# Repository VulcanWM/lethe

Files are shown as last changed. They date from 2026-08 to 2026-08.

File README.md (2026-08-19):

# Lethe

Lethe is an educational device aimed at reducing student's screen times by using a speaker to ask questions / convey informations, and using tilts to get user input.

## How it works
- load flashcard sets or MCQ sets onto the ESP32's USB-C connector (it must be in the JSON format expected by Lethe)
- select the flashcard set or MCQ set on the device by tilting through the list of all sets
- if in MCQ mode, a question will be spoken and each different direction responds an option, so to answer you tilt the device in a direction.
- the round will keep on going until all of the questions have been answered correctly
- if in flashcard mode, each flashcard's front side will be spoken out loud
- you can tilt up and down to flip the card and read the other side
- then you tilt left/right to signal whether you want it to be repeated or not

## Inspiration and component reasoning

I made it because high screen time is a problem I face myself, and this device means I can move around while studying. I also wanted to experiment and see if listening rather than reading helps to remember stuff more or not.

Some of the components I'm using and why:
- Seeed Studio XIAO ESP32-S3 Plus rather than not Plus because it has higher Flash and I'm using that to store all the flashcard sets.
- OLED display rather than a colour one because the screen will not be in use during the actual modes because I want the user to focus on sound rather than screens.
- An IMU (BMI270) so that I can accurately detect motions like tilting and flicking in all directions. This means I can use gestures instead of button clicking for user input.
- 1000 mAh LiPo Battery so that there is a reasonable battery life (5 hours) but it doesn't take too long to charge (10 hours).
- JST-PH 2-pin connector so that I can change the battery without needing to remove the solder.

## Hardware
This repository contains all the hardware files you would need to replicate this project. The PCB + schematics was done in the KiCad, and the enclosure was designed in Fusion 360.

The [`pcb-files`](pcb-files) folder contains the KiCad source files (`.kicad_sch`, `.kicad_pro`, `.kicad_pcb`) and the `gerbers.zip` which was used to manufacture the PCB.

The [`cad-files`](cad-files) folder contains `.step`, `.stl` and .`f3d` files for both the top and bottom cases of the enclosure for lethe.
## Firmware
There are 2 main components of the firmware: the code that will be uploaded onto the ESP32, and the code that will be used to transmit json sets on the user's device to the ESP32 when connected to the user's device via USB-C.

Both are located in the [`firmware-files`](firmware-files) folder: `lethe.ino` refers to the ESP32 code, and `upload.py` refers to the file transmission code.

## Assembly

The PCB is mounted to the bottom enclosure using three M2 self-tapping screws through the 2.2 mm mounting holes on the PCB and into standoffs printed as part of the enclosure. Then, the top and bottom parts of the enclosure are fitted together.

## Images
This is what the schematic looks like:
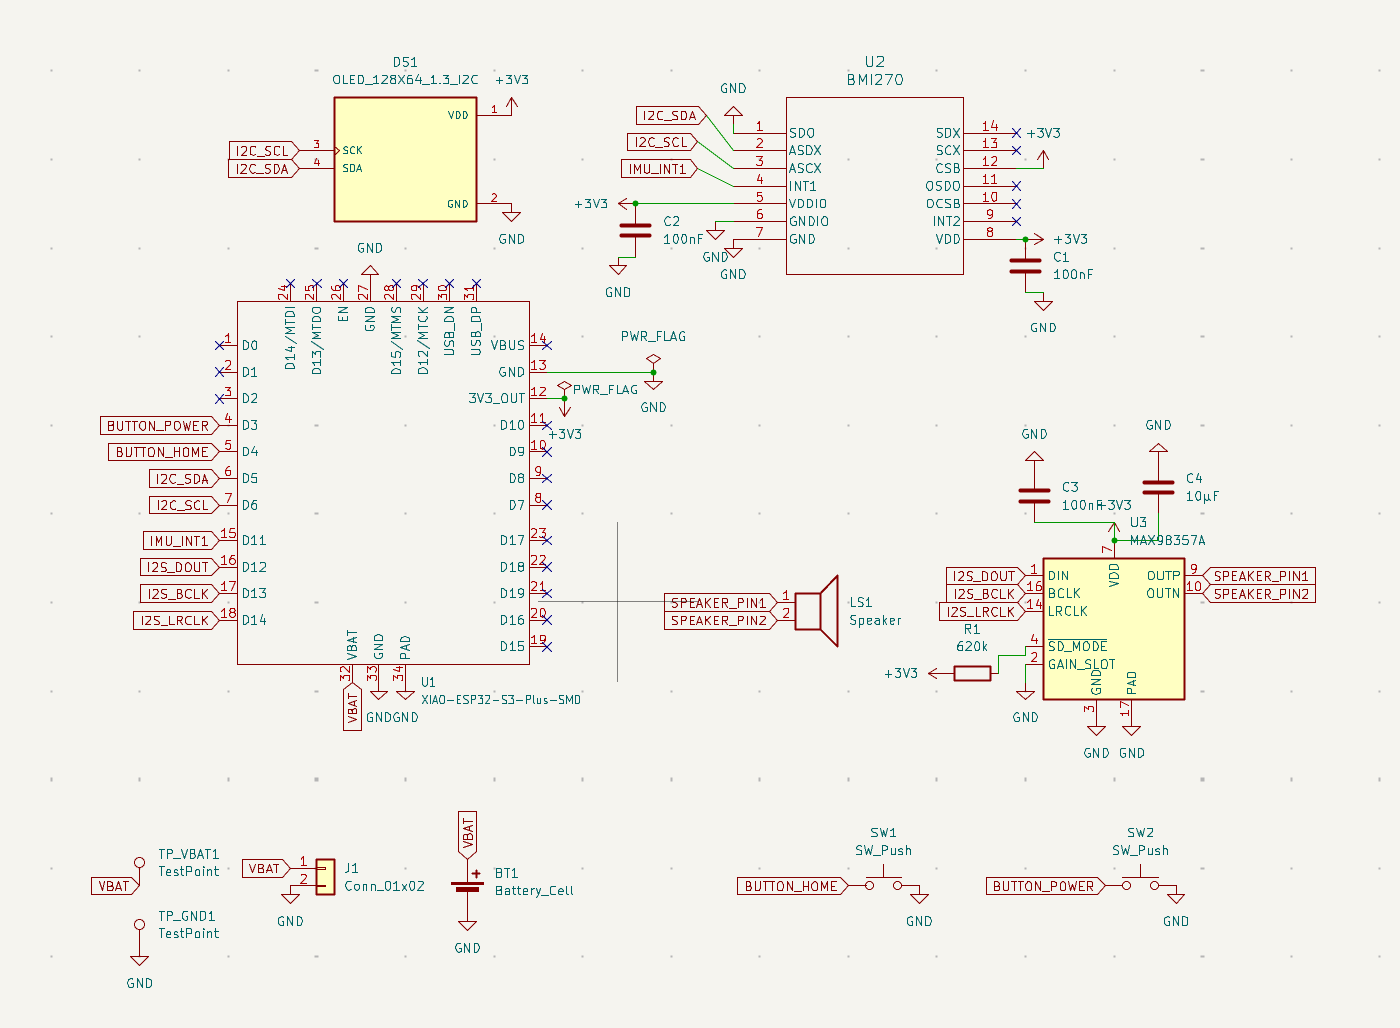
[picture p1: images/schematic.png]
schematic


This is what the PCB looks like:
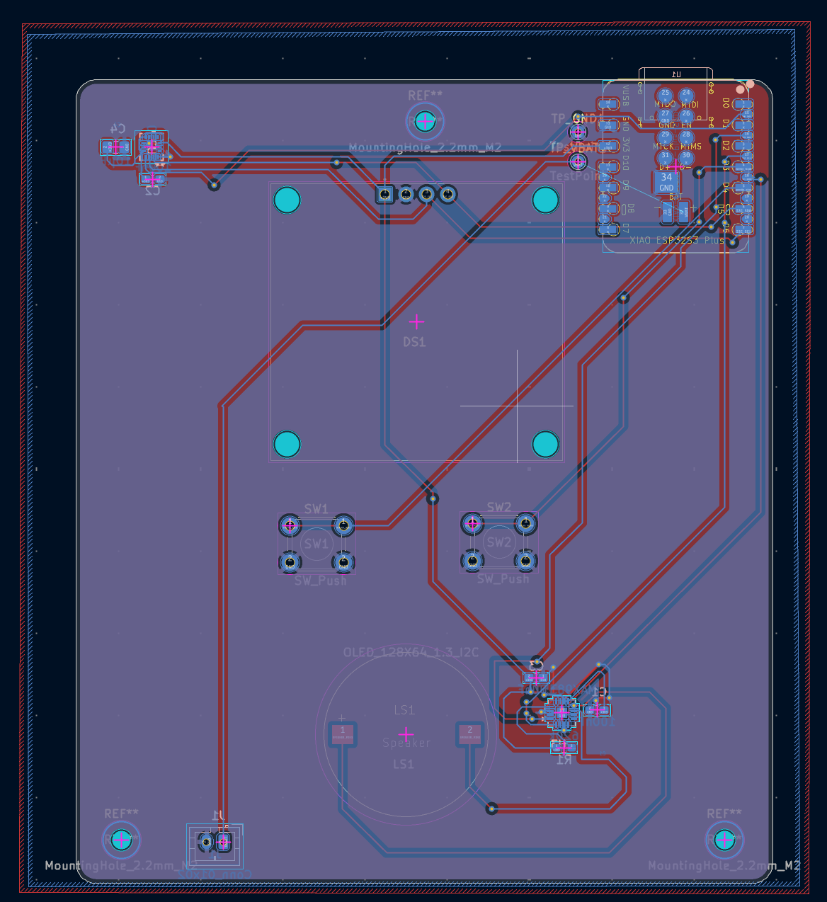
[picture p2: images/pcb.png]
pcb


This is what the enclosure (top and bottom case) looks like:
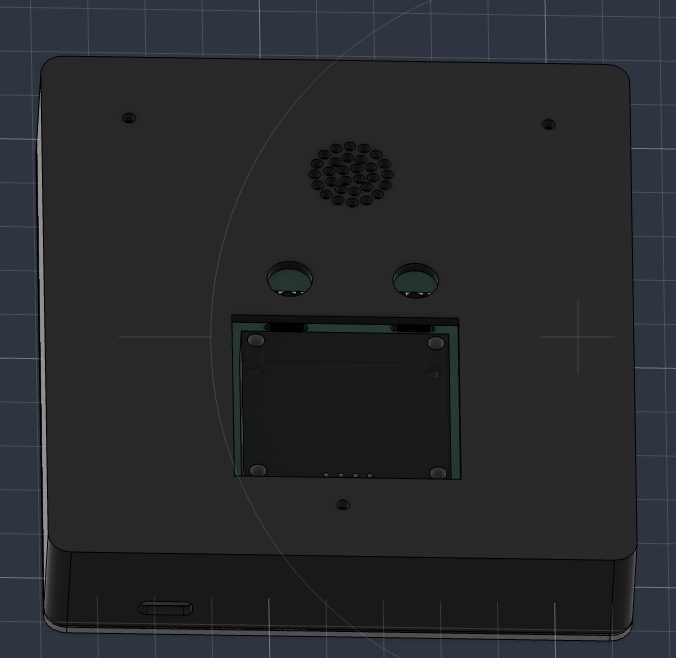
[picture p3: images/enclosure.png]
enclosure


## BOM
Also in the [BOM.csv](BOM.csv) file.

| Name | Quantity | Link To Buy | Cost (USD) |
|---|:---:|---|---|
| Seeed Studio XIAO ESP32-S3 Plus | 1 | [Seeed Studio](https://www.seeedstudio.com/Seeed-Studio-XIAO-ESP32S3-Plus-p-6361.html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) | $7.90 (+$3.80 shipping)  |
| Bosch BMI270 | 1 | [LCSC](https://www.lcsc.com/product-detail/C2836813.html?s_z=n_q_x_BMI270) | $3.64 |
| MAX98357A | 1 | [LCSC](https://www.lcsc.com/product-detail/C910544.html) | $1.34 |
| 1.3" SH1106 OLED | 1 | [AliExpress](https://www.aliexpress.com/item/1005006099414855.html) | $4.17 (shipping unknown) |
| JST-PH 2-pin Connector | 1 | [LCSC](https://www.lcsc.com/product-detail/C131337.html) | $0.71 for 20 |
| 20 mm 8Ω Speaker | 1 | [LCSC](https://www.lcsc.com/product-detail/C28642279.html) | $0.85 |
| Button | 2 | [LCSC](https://www.lcsc.com/product-detail/C393938.html) | $0.97 for 50 |
| 620 kΩ Resistor | 1 | [LCSC](https://www.lcsc.com/product-detail/C2096268.html) | $0.01 |
| 100 nF Ceramic Capacitor | 3 | [LCSC](https://www.lcsc.com/product-detail/C92490.html) | $1.81 for 50 |
| 10 µF Ceramic Capacitor | 1 | [LCSC](https://www.lcsc.com/product-detail/C17024.html) | $1.95 for 20 |
| 1000 mAh LiPo Battery | 1 | [AliExpress](https://www.aliexpress.com/item/1005009294502730.html) | $6.87 |
| **Total** | | | **$34.02 (excluding unknown AliExpress shipping)** |

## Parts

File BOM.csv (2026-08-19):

Name | Quantity | Link To Buy | Cost (USD)
Seeed Studio XIAO ESP32-S3 Plus | 1 | https://www.seeedstudio.com/Seeed-Studio-XIAO-ESP32S3-Plus-p-6361.html | $7.90 (+$3.80 shipping)
Bosch BMI270 | 1 | https://www.lcsc.com/product-detail/C2836813.html?s_z=n_q_x_BMI270 | $3.64
MAX98357A | 1 | https://www.lcsc.com/product-detail/C910544.html?s_z=n_q_MAX98357AETE%2520T | $1.34
1.3 inch SH1106 OLED | 1 | https://www.aliexpress.com/item/1005006099414855.html | $4.17 (shipping unknown)
JST-PH 2-pin Connector | 1 | https://www.lcsc.com/product-detail/C131337.html?s_z=n_q_JST%2520B2B-PH-K-S%28LF%29%28SN%29 | $0.71 for 20
20 mm 8 ohm Speaker | 1 | https://www.lcsc.com/product-detail/C28642279.html?s_z=n_q_20mm%25208ohm%2520speaker | $0.85
Button | 2 | https://www.lcsc.com/product-detail/C393938.html?s_z=n_q_SHOU%2520HAN%2520TS665CJ | $0.97 for 50
620 kΩ Resistor | 1 | https://www.lcsc.com/product-detail/C2096268.html?s_z=s_p_CRG0603F620K | $0.01
100 nF Ceramic Capacitor | 3 | https://www.lcsc.com/product-detail/C92490.html?s_z=n_q_100nF%25200603%2520X7R%252025V | $1.81 for 50
10 µF Ceramic Capacitor | 1 | https://www.lcsc.com/product-detail/C17024.html?s_z=n_q_10uF%25200805%2520X5R%252010V | $1.95 for 20
1000 mAh LiPo Battery | 1 | https://www.aliexpress.com/item/1005009294502730.html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 | $6.87
Total |  |  | $34.02 (excluding unknown AliExpress shipping)

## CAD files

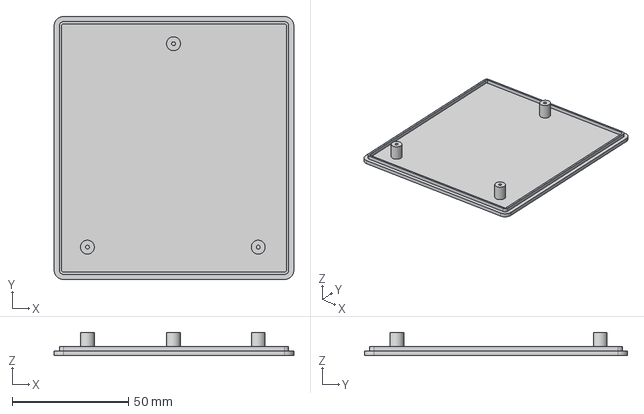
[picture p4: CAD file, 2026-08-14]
cad-files/bottom-case/BottomCase.step
103.0 x 113.0 x 10.0 mm

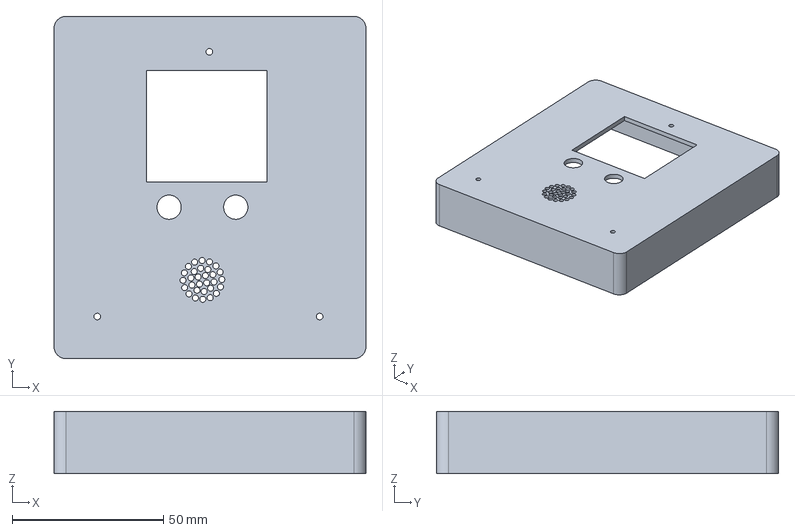
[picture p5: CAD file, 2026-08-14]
cad-files/top-case/TopCase.step
103.0 x 113.0 x 20.5 mm

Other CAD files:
cad-files/bottom-case/BottomCase.f3d
cad-files/bottom-case/BottomCase.stl
cad-files/top-case/TopCase.f3d
cad-files/top-case/TopCase.stl

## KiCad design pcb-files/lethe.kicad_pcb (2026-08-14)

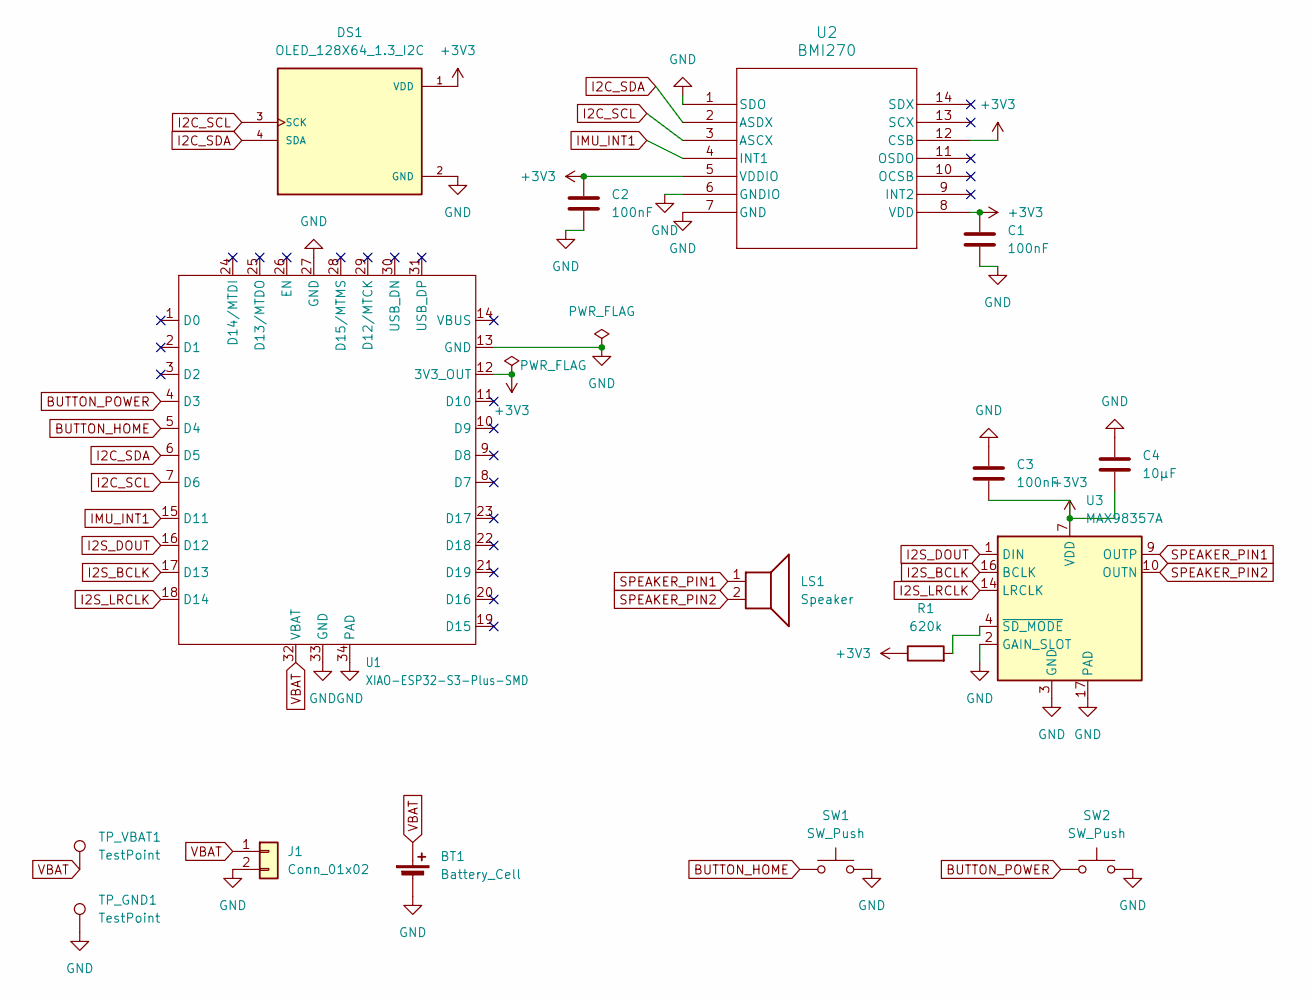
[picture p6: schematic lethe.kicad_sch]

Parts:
BT1: Battery_Cell
C1, C2, C3: 100nF; C_0603_1608Metric_Pad1.08x0.95mm_HandSolder
C4: 10µF; C_0805_2012Metric_Pad1.18x1.45mm_HandSolder
DS1: OLED_128X64_1.3_I2C; LCD_OLED_128X64_1.3_I2C; PARTREV NA
J1: Conn_01x02; JST_PH_B2B-PH-K_1x02_P2.00mm_Vertical
LS1: Speaker; Speaker_HDK2008AA_1P2_20mm
R1: 620k; R_0603_1608Metric_Pad0.98x0.95mm_HandSolder
SW1, SW2: SW_Push; SW_PUSH_6mm_H5mm
TP_GND1: TestPoint; TestPoint_THTPad_D1.5mm_Drill0.7mm
TP_VBAT1: TestPoint; TestPoint_THTPad_D1.5mm_Drill0.7mm
U1: XIAO-ESP32-S3-Plus-SMD
U2: BMI270; BMI270_BOS
U3: MAX98357A; TQFN-16-1EP_3x3mm_P0.5mm_EP1.23x1.23mm

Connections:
+3V3: C1.1, C2.1, C3.2, C4.2, DS1.1 (VDD), R1.1, U1.12 (3V3_OUT), U2.5 (VDDIO), U2.8 (VDD), U2.12 (CSB), U3.7 (VDD), U3.8 (VDD)
BUTTON_HOME: SW1.1, U1.5 (D4)
BUTTON_POWER: SW2.1, U1.4 (D3)
GND: BT1.2 (-), C1.2, C2.2, C3.1, C4.1, DS1.2 (GND), J1.2, SW1.2, SW2.2, TP_GND1.1 (1_1), U1.13 (GND), U1.27 (GND), U1.33 (GND), U1.34 (PAD), U2.1 (SDO), U2.6 (GNDIO), U2.7 (GND), U3.2 (GAIN_SLOT), U3.3 (GND), U3.11 (GND), U3.15 (GND), U3.17 (PAD)
I2C_SCL: DS1.3 (SCK), U1.7 (D6), U2.3 (ASCX)
I2C_SDA: DS1.4 (SDA), U1.6 (D5), U2.2 (ASDX)
I2S_BCLK: U1.17 (D13), U3.16 (BCLK)
I2S_DOUT: U1.16 (D12), U3.1 (DIN)
I2S_LRCLK: U1.18 (D14), U3.14 (LRCLK)
IMU_INT1: U1.15 (D11), U2.4 (INT1)
unnamed: R1.2, U3.4 (~SD_MODE)
SPEAKER_PIN1: LS1.1, U3.9 (OUTP)
SPEAKER_PIN2: LS1.2, U3.10 (OUTN)
VBAT: BT1.1 (+), J1.1, TP_VBAT1.1 (1_1), U1.32 (VBAT)

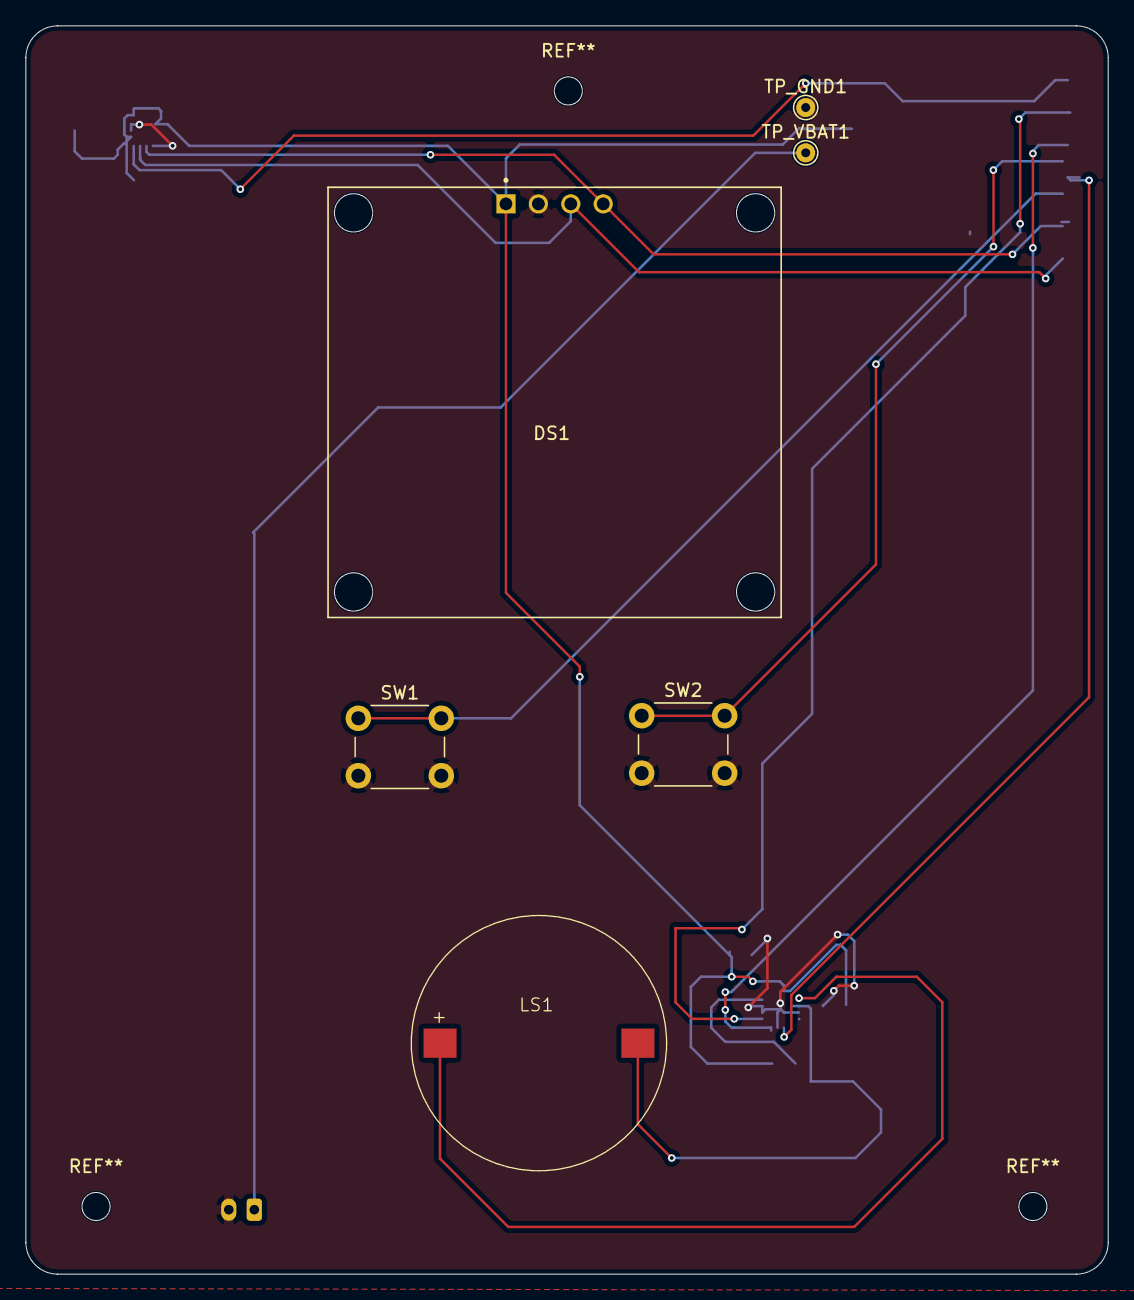
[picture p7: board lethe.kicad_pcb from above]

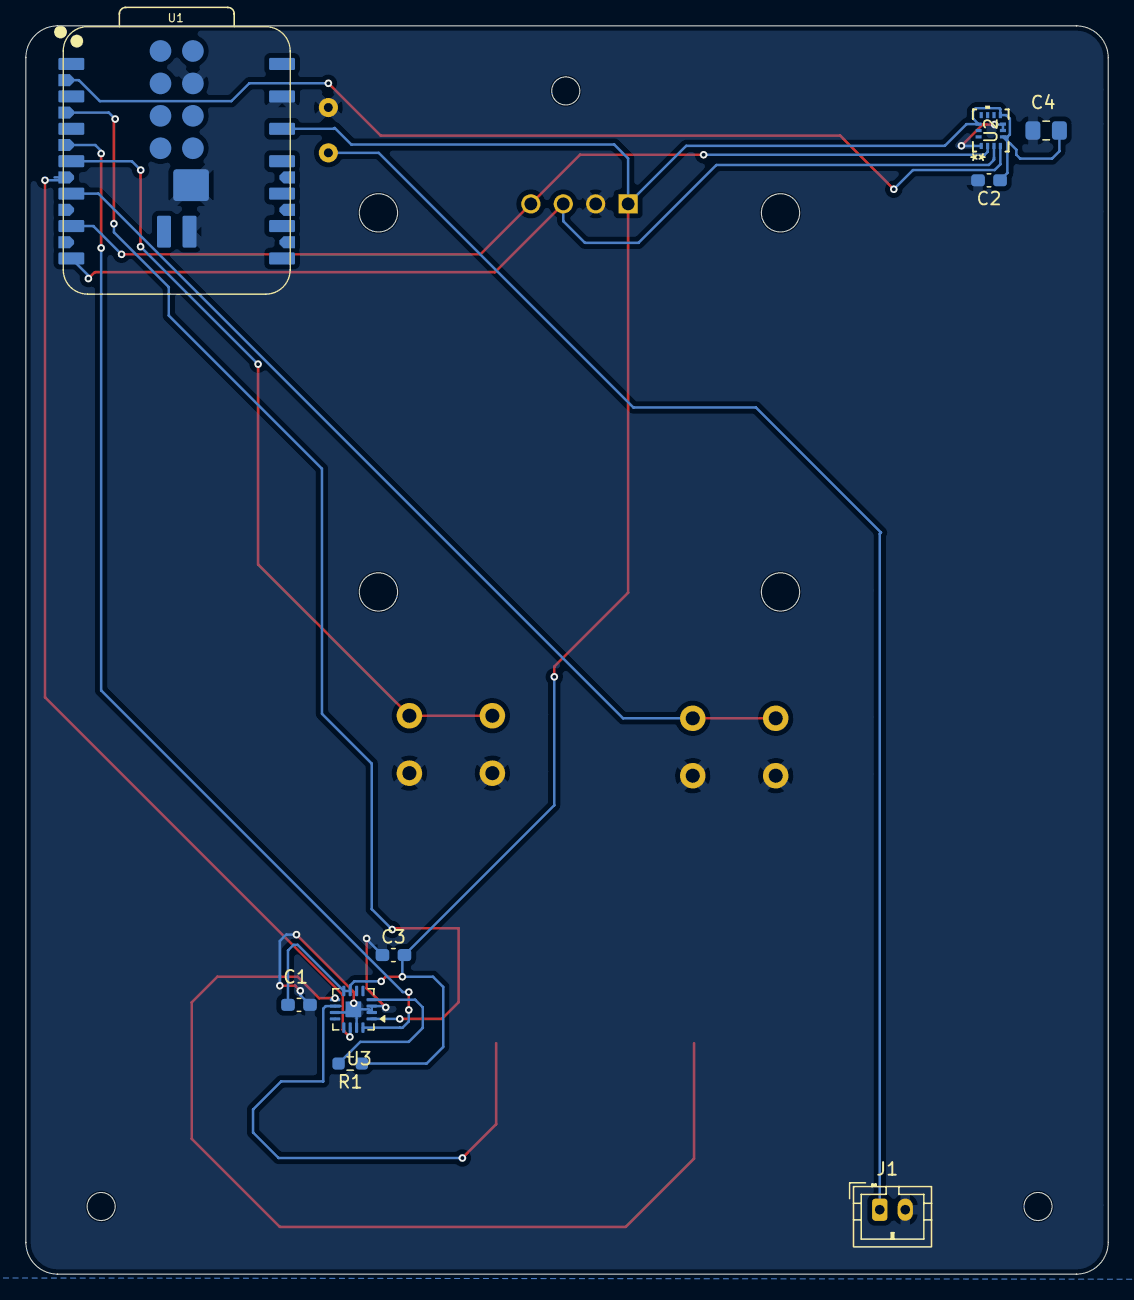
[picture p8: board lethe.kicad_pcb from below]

Board: 2 copper layers, 84.8 x 97.8 mm, 15 parts (9 on the bottom side), 14 nets.

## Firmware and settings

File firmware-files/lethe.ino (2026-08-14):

#include <Wire.h>
#include <U8g2lib.h>
#include <7Semi_BMI270.h>
#include <BackgroundAudioSpeech.h>
#include <ESP32I2SAudio.h>
#include <libespeak-ng/voice/en.h>
#include <esp_sleep.h>
#include "FS.h"
#include <LittleFS.h>
#include <ArduinoJson.h>
#include <vector>

// buttons
#define BUTTON_POWER D3
#define BUTTON_HOME D4

// i2c (for oled and imu)
#define SDA_PIN D5
#define SCL_PIN D6

// imu interrupt
#define IMU_INT1 D11

// i2s (for amplifier)
#define I2S_DOUT D12
#define I2S_BCLK D13
#define I2S_LRCLK D14

// for LittleFS
#define FORMAT_LITTLEFS_IF_FAILED true

bool initDirectories(){
  if (!LittleFS.exists("/mcqs")){
    if (!LittleFS.mkdir("/mcqs")){
      Serial.println("failed to create mcqs directory");
      return false;
    }
  };

  if (!LittleFS.exists("/flashcards")){
    if (!LittleFS.mkdir("/flashcards")){
      Serial.println("failed to create flashcards directory");
      return false;
    }
  };

  return true;
}

U8G2_SH1106_128X64_NONAME_F_HW_I2C display(
  U8G2_R0,
  U8X8_PIN_NONE
);

BMI270_7Semi imu;

ESP32I2SAudio audio(
  I2S_BCLK,
  I2S_LRCLK,
  I2S_DOUT
);

BackgroundAudioSpeech speech(audio);

enum Gesture {
  NONE,

  TILT_UP,
  TILT_DOWN,
  TILT_LEFT,
  TILT_RIGHT,

  FLICK_UP,
  FLICK_DOWN,
  FLICK_LEFT,
  FLICK_RIGHT,

  SPIN,
};

enum TILT_STATE {
  TILT_NEUTRAL,
  TILT_WAITING_RETURN_RIGHT,
  TILT_WAITING_RETURN_LEFT,
  TILT_WAITING_RETURN_UP,
  TILT_WAITING_RETURN_DOWN
};

enum FLICK_STATE {
  FLICK_NEUTRAL,
  FLICK_WAITING_RETURN_RIGHT,
  FLICK_WAITING_RETURN_LEFT,
  FLICK_WAITING_RETURN_UP,
  FLICK_WAITING_RETURN_DOWN,
};

enum FACE_STATE {
  FACE_UP,
  FACE_DOWN
};

enum DEVICE_STATE {
  HOME,
  MCQ_SET_MENU,
  FLASHCARD_SET_MENU,
  MCQ_ACTIVE,
  FLASHCARD_ACTIVE
};

const char* gestureToString(Gesture gesture);
Gesture detectTilt(float ax, float ay, float az);
Gesture detectFlick(float ax, float ay, float az);
Gesture detectSpin(float ax, float ay, float az);
Gesture detectGesture(float ax, float ay, float az);

TILT_STATE tiltState = TILT_NEUTRAL;
FLICK_STATE flickState = FLICK_NEUTRAL;
FACE_STATE faceState = FACE_UP;
DEVICE_STATE deviceState = HOME;

bool mcqSetsChanged = true;
bool flashcardSetsChanged = true;
String setSelected;

const char* gestureToString(Gesture gesture){
  switch (gesture){
    case TILT_UP: return "tilt up";
    case TILT_DOWN: return "tilt down";
    case TILT_LEFT: return "tilt left";
    case TILT_RIGHT: return "tilt right";

    case FLICK_UP: return "flick up";
    case FLICK_DOWN: return "flick down";
    case FLICK_LEFT: return "flick left";
    case FLICK_RIGHT: return "flick right";

    case SPIN: return "spin";

    default: return "none";
  }
}

Gesture detectTilt(float ax, float ay, float az){
  const float tiltThreshold = 0.7;
  const float neutralThreshold = 0.25;

  if (tiltState == TILT_NEUTRAL){
    if (ax > tiltThreshold){
      tiltState = TILT_WAITING_RETURN_RIGHT;
    }
    else if (ax < (-1 * tiltThreshold)){
      tiltState = TILT_WAITING_RETURN_LEFT;
    }
    else if (ay > tiltThreshold){
      tiltState = TILT_WAITING_RETURN_UP;
    }
    else if (ay < (-1 * tiltThreshold)){
      tiltState = TILT_WAITING_RETURN_DOWN;
    }
  }

  if (tiltState == TILT_WAITING_RETURN_DOWN){
    if (abs(ax) < neutralThreshold && abs(ay) < neutralThreshold){
      tiltState = TILT_NEUTRAL;
      return TILT_DOWN;
    }
  }
  if (tiltState == TILT_WAITING_RETURN_UP) {
    if (abs(ax) < neutralThreshold && abs(ay) < neutralThreshold){
      tiltState = TILT_NEUTRAL;
      return TILT_UP;
    }
  }

  if (tiltState == TILT_WAITING_RETURN_LEFT){
    if (abs(ax) < neutralThreshold && abs(ay) < neutralThreshold){
      tiltState = TILT_NEUTRAL;
      return TILT_LEFT;
    }
  }

  if (tiltState == TILT_WAITING_RETURN_RIGHT){
    if (abs(ax) < neutralThreshold && abs(ay) < neutralThreshold){
      tiltState = TILT_NEUTRAL;
      return TILT_RIGHT;
    }
  }
  return NONE;
}

Gesture detectFlick(float ax, float ay, float az){
  const float flickThreshold = 1.5;
  const float neutralThreshold = 0.25;

  if (flickState == FLICK_NEUTRAL){
    if (ax > flickThreshold){
      flickState = FLICK_WAITING_RETURN_RIGHT;
    }
    else if (ax < (-1 * flickThreshold)){
      flickState = FLICK_WAITING_RETURN_LEFT;
    }
    else if (ay > flickThreshold){
      flickState = FLICK_WAITING_RETURN_UP;
    }
    else if (ay < (-1 * flickThreshold)){
      flickState = FLICK_WAITING_RETURN_DOWN;
    }
  }

  if (flickState == FLICK_WAITING_RETURN_DOWN){
    if (abs(ax) < neutralThreshold && abs(ay) < neutralThreshold){
      flickState = FLICK_NEUTRAL;
      return FLICK_DOWN;
    }
  }
  if (flickState == FLICK_WAITING_RETURN_UP) {
    if (abs(ax) < neutralThreshold && abs(ay) < neutralThreshold){
      flickState = FLICK_NEUTRAL;
      return FLICK_UP;
    }
  }

  if (flickState == FLICK_WAITING_RETURN_LEFT){
    if (abs(ax) < neutralThreshold && abs(ay) < neutralThreshold){
      flickState = FLICK_NEUTRAL;
      return FLICK_LEFT;
    }
  }

  if (flickState == FLICK_WAITING_RETURN_RIGHT){
    if (abs(ax) < neutralThreshold && abs(ay) < neutralThreshold){
      flickState = FLICK_NEUTRAL;
      return FLICK_RIGHT;
    }
  }
  return NONE;
}

Gesture detectSpin(float ax, float ay, float az){
  const float faceDownThreshold = -0.8;
  const float faceUpThreshold = 0.8;

  if (faceState == FACE_UP && az < faceDownThreshold){
    faceState = FACE_DOWN;
  }

  if (faceState == FACE_DOWN && az > faceUpThreshold){
    faceState = FACE_UP;
    return SPIN;
  }

  return NONE;
}

Gesture detectGesture(float ax, float ay, float az){
  Gesture gesture;

  if (flickState != FLICK_NEUTRAL){
    return detectFlick(ax, ay, az);
  }

  if (tiltState != TILT_NEUTRAL){
    return detectTilt(ax, ay, az);
  }

  if (faceState != FACE_UP){
    return detectSpin(ax, ay, az);
  }

  gesture = detectFlick(ax, ay, az);
  if (flickState != FLICK_NEUTRAL){
    return gesture;
  }

  gesture = detectTilt(ax, ay, az);
  if (tiltState != TILT_NEUTRAL){
    return gesture;
  }

  gesture = detectSpin(ax, ay, az);
  return gesture;
}

void powerOff(){
  display.clearBuffer();
  display.sendBuffer();

  speech.flush();

  delay(100);

  esp_sleep_enable_ext0_wakeup(
    (gpio_num_t)BUTTON_POWER,
    0
  );

  esp_deep_sleep_start();
}

bool validateMCQJSON(const String& json){
  JsonDocument doc;

  DeserializationError error = deserializeJson(doc, json);

  if (error){
    Serial.println("invalid json");
    return false;
  }

  if (!doc["name"].is<const char*>()){
    Serial.println("missing/invalid name");
    return false;
  }

  if (!doc["questions"].is<JsonArray>()){
    Serial.println("missing questions array");
    return false;
  }

  JsonArray questions = doc["questions"];

  if (questions.size() == 0){
    Serial.println("no questions");
    return false;
  }

  for (JsonObject question: questions){
    if (!question["question"].is<const char*>()){
      Serial.println("invalid question");
      return false;
    }

    if (!question["options"].is<JsonArray>()){
      Serial.println("ERROR: missing/invalid options");
      return false;
    }

    JsonArray options = question["options"];

    if (options.size() < 2 || options.size() > 4){
      Serial.println("mcq must have between 2 and 4 options");
      return false;
    }

    for (JsonVariant option: options){
      if (!option.is<const char*>()){
        Serial.println("option must be text");
        return false;
      }
    }

    if (!question["answer"].is<int>()){
      Serial.println("invalid answer");
      return false;
    }

    int answer = question["answer"];
    if (answer < 0 || answer >= options.size()){
      Serial.print("answer must be between 0-");
      Serial.println(options.size()-1);
      return false;
    }
  }

  return true;
}

bool validateFlashcardJSON(const String& json){
  JsonDocument doc;

  DeserializationError error = deserializeJson(doc, json);

  if (error){
    Serial.println("ERROR: invalid json");
    return false;
  }

  if (!doc["name"].is<const char*>()){
    Serial.println("ERROR: missing/invalid json");
    return false;
  }

  if (!doc["cards"].is<JsonArray>()){
    Serial.println("ERROR: missing cards array");
    return false;
  }

  JsonArray cards = doc["cards"];

  if (cards.size() == 0){
    Serial.println("ERROR: no flashcards");
    return false;
  }

  for (JsonObject card: cards){
    if (!card["front"].is<const char*>()){
      Serial.println("ERROR: invalid front");
      return false;
    }

    if (!card["back"].is<const char*>()){
      Serial.println("ERROR: invalid back");
      return false;
    }
  }

  return true;
}

bool validateSet(const String& type, const String& json){
  if (type == "MCQ"){
    return validateMCQJSON(json);
  }

  if (type == "FLASHCARD"){
    return validateFlashcardJSON(json);
  }

  return false;
}

bool validateTempFile(const String& type){
  File file = LittleFS.open("/tmp.json", FILE_READ);

  if (!file){
    Serial.println("ERROR: failed to open temp file");
    return false;
  }

  String json = file.readString();
  file.close();

  return validateSet(type, json);
}

JsonDocument parseMCQSet(const String& setName){
  JsonDocument doc;

  String filePath = "/mcqs/" + setName;

  if (!LittleFS.exists(filePath)){
    Serial.println("file does not exist");
    return doc;
  }

  File file = LittleFS.open(filePath);
  if (!file){
    Serial.println("file is not opening");
    return doc;
  }

  String json = file.readString();
  file.close();

  DeserializationError error = deserializeJson(doc, json);

  return doc;
}

JsonDocument parseFlashcardSet(const String& setName){
  JsonDocument doc;

  String filePath = "/flashcards/" + setName;

  if (!LittleFS.exists(filePath)){
    Serial.println("file does not exist");
    return doc;
  }

  File file = LittleFS.open(filePath);
  if (!file){
    Serial.println("file is not opening");
    return doc;
  }

  String json = file.readString();
  file.close();

  DeserializationError error = deserializeJson(doc, json);

  return doc;
}

bool moveTempFile(const String& finalPath){
  if (LittleFS.exists(finalPath)){
    LittleFS.remove(finalPath);
  }

  if (!LittleFS.rename("/tmp.json", finalPath)){
    Serial.println("ERROR: failed to move temp file");
    return false;
  }

  return true;
}

void checkUSB(){
  if (Serial.available()){
    String command = Serial.readStringUntil('\n');
    command.trim();

    if (command == "PING"){
      Serial.println("PONG");
      return;
    }

    if (command == "UPLOAD"){
      String type = Serial.readStringUntil('\n');
      String name = Serial.readStringUntil('\n');
      String sizeString = Serial.readStringUntil('\n');

      type.trim();
      name.trim();
      sizeString.trim();

      size_t fileSize = sizeString.toInt();

      if (name.length() == 0 ||
          name.indexOf('/') != -1 ||
          name.indexOf('\\') != -1 ||
          !name.endsWith(".json")){
        Serial.println("ERROR: invalid filename");
        return;
      }

      String finalPath;

      if (type == "MCQ"){
        finalPath = "/mcqs/" + name;
      } else if (type == "FLASHCARD"){
        finalPath = "/flashcards/" + name;
      } else {
        Serial.println("ERROR: invalid type");
        return;
      }

      if (LittleFS.exists("/tmp.json")){
        LittleFS.remove("/tmp.json");
      }

      File tempFile = LittleFS.open("/tmp.json", FILE_WRITE);
      if (!tempFile){
        Serial.println("ERROR: failed to open temp file");
        return;
      }

      size_t received = 0;

      while (received < fileSize){
        if (Serial.available()){
          uint8_t byte = Serial.read();
          tempFile.write(byte);
          received++;
        }
      }

      tempFile.close();

      if (!validateTempFile(type)){
        Serial.println("ERROR: invalid set");
        LittleFS.remove("/tmp.json");
        return;
      }

      if (!moveTempFile(finalPath)){
        Serial.println("ERROR: could not copy file into directory");
        LittleFS.remove("/tmp.json");
        return;
      }

      if (type == "MCQ"){
        mcqSetsChanged = true;
      } else if (type == "FLASHCARD"){
        flashcardSetsChanged = true;
      }

      Serial.println("OK");
    }
  }
}

void checkPowerButton(){
  static unsigned long pressedAt = 0;
  static bool holding = false;

  bool pressed = digitalRead(BUTTON_POWER) == LOW;

  if (pressed && !holding){
    holding = true;
    pressedAt = millis();
  }

  if (!pressed){
    holding = false;
  }

  if (holding && millis() - pressedAt >= 2000){
    powerOff();
  }
}

void checkHomeButton(){
  static bool wasPressed = false;

  bool pressed = digitalRead(BUTTON_HOME) == LOW;

  if (pressed && !wasPressed){
    display.clearBuffer();
    display.sendBuffer();

    speech.flush();
    deviceState = HOME;
  }

  wasPressed = pressed;
}

std::vector<String> getAllFlashcardSets(){
  std::vector<String> sets;
  File root = LittleFS.open("/flashcards");

  File file = root.openNextFile();

  if (!root || !root.isDirectory()){
    Serial.println("failed to open flashcards directory");
    return sets;
  }

  while (file){
    if (!file.isDirectory()){
      sets.push_back(String(file.name()));
    }

    file = root.openNextFile();
  }

  return sets;
}

std::vector<String> getAllMCQSets(){
  std::vector<String> sets;
  File root = LittleFS.open("/mcqs");

  if (!root || !root.isDirectory()){
    Serial.println("failed to open mcqs directory");
    return sets;
  }

  File file = root.openNextFile();
  while (file){
    if (!file.isDirectory()){
      sets.push_back(String(file.name()));
    }

    file = root.openNextFile();
  }

  return sets;
}

void updateHome(){
  static bool willNeedRender = true;
  static int menuOptionSelected = 0;

  float ax, ay, az;
  if (imu.readAccel(ax, ay, az)) {
    Gesture gesture = detectGesture(ax, ay, az);
    if (gesture == TILT_UP){
      if (menuOptionSelected == 1){
        menuOptionSelected = 0;
        willNeedRender = true;
      }
    }
    else if (gesture == TILT_DOWN){
      if (menuOptionSelected == 0){
        menuOptionSelected = 1;
        willNeedRender = true;
      }
    }
    else if (gesture == TILT_RIGHT){
      if (menuOptionSelected == 0){
        deviceState = MCQ_SET_MENU;
      } else {
        deviceState = FLASHCARD_SET_MENU;
      }
      willNeedRender = true;
      return;
    }
  }

  if (willNeedRender){
    display.clearBuffer();
    display.setFont(u8g2_font_6x12_tf);
    display.setCursor(0, 10);
    display.print("lethe");

    display.setCursor(0, 20);
    if (menuOptionSelected == 0){
      display.print("> MCQs");
    } else {
      display.print(" MCQs");
    }

    display.setCursor(0, 30);
    if (menuOptionSelected == 1){
      display.print("> Flashcards");
    } else {
      display.print("Flashcards");
    }

    display.sendBuffer();
    willNeedRender = false;
  }
}

void updateMCQMenu(){
  static bool willNeedRender = true;
  static int menuOptionSelected = 0;
  static std::vector<String> sets = getAllMCQSets();

  if (mcqSetsChanged){
    sets = getAllMCQSets();
    mcqSetsChanged = false;

    menuOptionSelected = 0;
    willNeedRender = true;
  }

  float ax, ay, az;
  if (imu.readAccel(ax, ay, az)) {
    Gesture gesture = detectGesture(ax, ay, az);
    if (gesture == TILT_UP){
      if (!sets.empty() && menuOptionSelected != 0){
        menuOptionSelected -= 1;
        willNeedRender = true;
      }
    }
    else if (gesture == TILT_DOWN){
      if (!sets.empty() && menuOptionSelected != sets.size() - 1){
        menuOptionSelected += 1;
        willNeedRender = true;
      }
    }
    else if (gesture == TILT_RIGHT){
      if (!sets.empty()){
        deviceState = MCQ_ACTIVE;
        setSelected = sets[menuOptionSelected];
        willNeedRender = true;
        return;
      }
    }
    else if (gesture == TILT_LEFT){
      deviceState = HOME;
      willNeedRender = true;
    }
  }

  if (willNeedRender){
    display.clearBuffer();
    display.setFont(u8g2_font_6x12_tf);
    if (sets.empty()){
      display.setCursor(0, 10);
      display.print("no mcq sets");
    } else {
      int y = 10;
      for (int i=menuOptionSelected; i < menuOptionSelected+4; i++) {
        display.setCursor(0, y);
        if (i < sets.size()){
          if (i == menuOptionSelected){
            display.print("> ");
          } else {
            display.print("  ");
          }
          display.print(sets[i]);
        }
        y += 10;
      }
    }
    display.sendBuffer();
    willNeedRender = false;
  }
}

void updateFlashcardMenu(){
  static bool willNeedRender = true;
  static int menuOptionSelected = 0;
  static std::vector<String> sets = getAllFlashcardSets();

  if (flashcardSetsChanged){
    sets = getAllFlashcardSets();
    flashcardSetsChanged = false;

    menuOptionSelected = 0;
    willNeedRender = true;
  }

  float ax, ay, az;
  if (imu.readAccel(ax, ay, az)){
    Gesture gesture = detectGesture(ax, ay, az);
    if (gesture == TILT_UP){
      if (!sets.empty() && menuOptionSelected != 0){
        menuOptionSelected -= 1;
        willNeedRender = true;
      }
    } else if (gesture == TILT_DOWN){
      if (!sets.empty() && menuOptionSelected != sets.size() - 1){
        menuOptionSelected += 1;
        willNeedRender = true;
      }
    } else if (gesture == TILT_RIGHT){
      if (!sets.empty()){
        deviceState = FLASHCARD_ACTIVE;
        setSelected = sets[menuOptionSelected];
        willNeedRender = true;
        return;
      }
    } else if (gesture == TILT_LEFT){
      deviceState = HOME;
      willNeedRender = true;
    }
  }

  if (willNeedRender){
    display.clearBuffer();
    display.setFont(u8g2_font_6x12_tf);
    if (sets.empty()){
      display.setCursor(0, 10);
      display.print("no flashcard sets");
    } else {
      int y = 10;
      for (int i=menuOptionSelected; i < menuOptionSelected+4; i++){
        display.setCursor(0, y);
        if (i < sets.size()){
          if (i == menuOptionSelected){
            display.print("> ");
          } else {
            display.print("  ");
          }
          display.print(sets[i]);
        }
        y += 10;
      }
    }
    display.sendBuffer();
    willNeedRender = false;
  }
}

void updateMCQ(){
  static JsonDocument doc = parseMCQSet(setSelected);

  static std::vector<int> questionsToDo;
  static std::vector<int> questionsWrong;
  static std::vector<int> questionsRight;
  static int currentQuestionIndex = -1;

  static bool waitingForInput = false;
  static bool needsSetup = true;

  if (needsSetup) {
    doc = parseMCQSet(setSelected);
    JsonArray questions = doc["questions"];

    questionsToDo.clear();
    questionsWrong.clear();
    questionsRight.clear();

    for (int i = 0; i < questions.size(); i++) {
      questionsToDo.push_back(i);
    }

    currentQuestionIndex = -1;
    waitingForInput = false;
    needsSetup = false;
  }

  if (waitingForInput){
    JsonObject currentQuestion = doc["questions"][currentQuestionIndex];

    float ax, ay, az;
    if (imu.readAccel(ax, ay, az)){
      Gesture gesture = detectGesture(ax, ay, az);
      if (gesture != NONE){
        if (gesture == SPIN){
          needsSetup = true;
          deviceState = MCQ_SET_MENU;
          return;
        } else {
          if ((gesture == TILT_UP && currentQuestion["answer"] == 0)
          || (gesture == TILT_RIGHT && currentQuestion["answer"] == 1)
          || (gesture == TILT_DOWN && currentQuestion["answer"] == 2)
          || (gesture == TILT_LEFT && currentQuestion["answer"] == 3)){
            speech.speak("Correct.");
            questionsRight.push_back(currentQuestionIndex);
          } else {
            int answer = currentQuestion["answer"];
            String correctAnswer = currentQuestion["options"][answer].as<String>();
            speech.speak("Wrong. The correct answer is " + correctAnswer);
            questionsWrong.push_back(currentQuestionIndex);
          }
          waitingForInput = false;
        }
      }
    }
  } else {
    if (questionsToDo.empty()){
      if (questionsWrong.empty()){
        speech.speak("Well done. You finished all the questions.");
        needsSetup = true;
        deviceState = MCQ_SET_MENU;
        return;
      } else {
        questionsToDo = questionsWrong;
        questionsWrong.clear();
      }
    } else {
      int randomIndex = random(questionsToDo.size());
      currentQuestionIndex = questionsToDo[randomIndex];
      questionsToDo.erase(questionsToDo.begin() + randomIndex);

      JsonObject currentQuestion = doc["questions"][currentQuestionIndex];
      String toSpeak = currentQuestion["question"].as<String>();
      JsonArray options = currentQuestion["options"];

      for (int i = 0; i < options.size(); i++) {
        toSpeak += ". Option ";
        toSpeak += String(i + 1);
        toSpeak += ". ";
        toSpeak += options[i].as<String>();
      }

      speech.speak(toSpeak);
      waitingForInput = true;
    }
  }
}
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
void loop() {
  checkPowerButton();
  checkHomeButton();
  checkUSB();

  switch (deviceState) {
    case HOME:
      updateHome();
      break;

    case MCQ_SET_MENU:
      updateMCQMenu();
      break;

    case FLASHCARD_SET_MENU:
      updateFlashcardMenu();
      break;

    case MCQ_ACTIVE:
      updateMCQ();
      break;

    case FLASHCARD_ACTIVE:
      updateFlashcard();
      break;
  }

  delay(20);
}

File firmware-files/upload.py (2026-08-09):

import os
import sys
import time
import serial
import serial.tools.list_ports

BAUD_RATE = 115200

def find_port():
    ports = list(serial.tools.list_ports.comports())

    if not ports:
        print("no serial ports found")
        sys.exit(1)

    print("available ports: ")

    for i, port in enumerate(ports):
        print(f"{i}: {port.device} - {port.description}")

    choice = int(input("pick lethe's port: "))
    return ports[choice].device

def upload_file(port_name, file_path, set_type):
    if set_type not in ["MCQ", "FLASHCARD"]:
        print("type must be MCQ or FLASHCARD")
        return

    if not os.path.exists(file_path):
        print("file does not exist")
        return

    filename = os.path.basename(file_path)

    with open(file_path, "rb") as f:
        data = f.read()

    file_size = len(data)

    with serial.Serial(port_name, BAUD_RATE, timeout=5) as ser:
        time.sleep(2)

        ser.write(b"UPLOAD\n")
        ser.write((set_type + "\n").encode())
        ser.write((filename + "\n").encode())
        ser.write((str(file_size) + "\n").encode())

        ser.write(data)
        ser.flush()

        print(f"sent {file_size} bytes")

        response = ser.readline().decode(errors="ignore").strip()

        if response == "OK":
            print("upload successful")
        else:
            print("device response: ", response)

def main():
    if len(sys.argv) != 3:
        print("usage:")
        print("python upload.py <MCQ|FLASHCARD> <file.json>")
        return

    set_type = sys.argv[1].upper()
    file_path = sys.argv[2]

    port = find_port()

    upload_file(port, file_path, set_type)

if __name__ == "__main__":
    main()

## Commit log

2026-08-07 Initialize lethe.ino with button and pin definitions
2026-08-07 writing on the oled and getting input from buttons
2026-08-07 getting data from the imu
2026-08-08 converted to ESP32I2SAudio for amplifier
2026-08-08 added going into deep sleep via power button
2026-08-09 added checking for home button press and skeleton for main ui
2026-08-14 added enclosure files
    [BottomCase.f3d, BottomCase.step, BottomCase.stl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]
2026-08-14 added BOM
    [BOM.csv]
2026-08-14 added pcb/schematics files
    [lethe.kicad_pcb, lethe.kicad_sch]
2026-08-14 renamed `enclosure-files` to `cad-files`
    [BottomCase.f3d, BottomCase.step, BottomCase.stl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]
2026-08-18 Add assembly section to README
2026-08-18 Fix screw count for PCB mounting in README
    Corrected the number of screws used to mount the PCB.
2026-08-19 Update BOM.csv with new entries and total cost
    [BOM.csv]
